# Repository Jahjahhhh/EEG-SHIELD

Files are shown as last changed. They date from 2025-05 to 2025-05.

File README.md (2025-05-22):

# EEG-SHIELD

Electroencephalography (EEG) acquisition system. Using TI's ADS1299-4 low noise, programmable gain amplifier, 4 channel ADC.
The data is sent to a PC using SPI (raspberry pi in this case) to view measured signals. In order to not lose any bits of data, 
we use a microcontroller (ESP32) to interface with the ADS1299 and relay information to the Raspberry Pi 3B+ (the Pi is busy interrupting, it is running an OS).

---

## Project File Structure

| Folder | Contents |
|---|---|
| `KiCAD/` | Main KiCad project files |
| `KiCAD/gerbers`  | KiCad gerber files |
| `KiCAD/images` | Images used in KiCad |
| `KiCAD/libraries`| KiCad footprints and symbols |
| `PDFs/` | Useful PDFs for the project |
| `images/` | Images for the Github repository |
| `source/projet6` | The ESP32 code directory |
| `source/projet6/compile-upload-monitor.sh` | Script to build and monitor arduino script  |
| `source/projet6/definitions.h` | #define (register definitions, etc) |
| `source/projet6/functions.h` | Custom functions  |
| `source/projet6/projet6.sh` | Main Arduino sketch, runs the functions in `functions.h`  |
| `source/pi` | The RPi code directory |
| `source/pi/main.py` | Reads data from ESP32 and formats it into data.txt |
| `source/pi/data.txt` | Raw data to be graphed |
| `source/pi/plot.py` | Reads `source/pi/data.txt` to generate a graph |
---

## Images

### Schematics
#### Raspberry Pi 3B+ Circuit
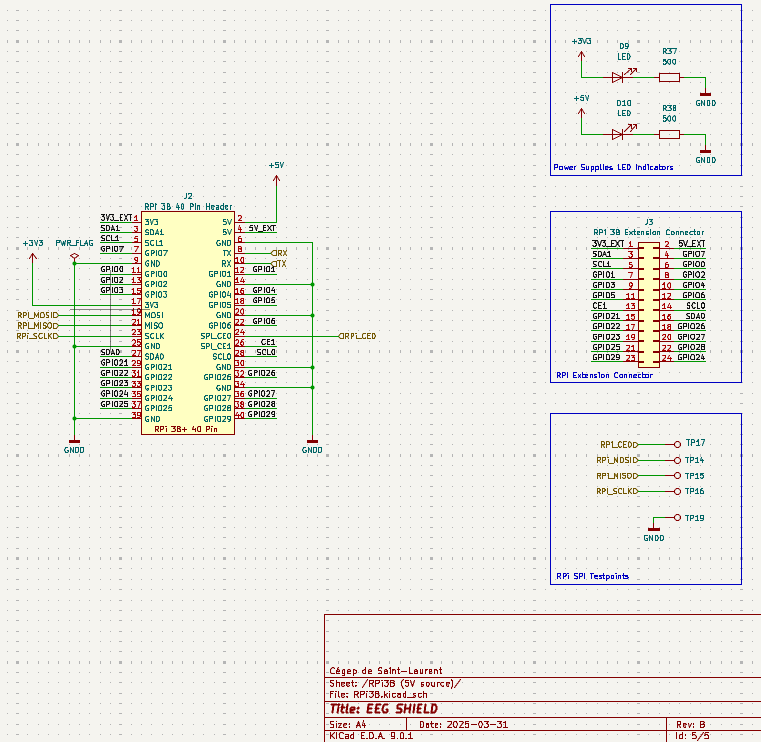
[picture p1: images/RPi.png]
Schematic

#### ESP32 Circuit
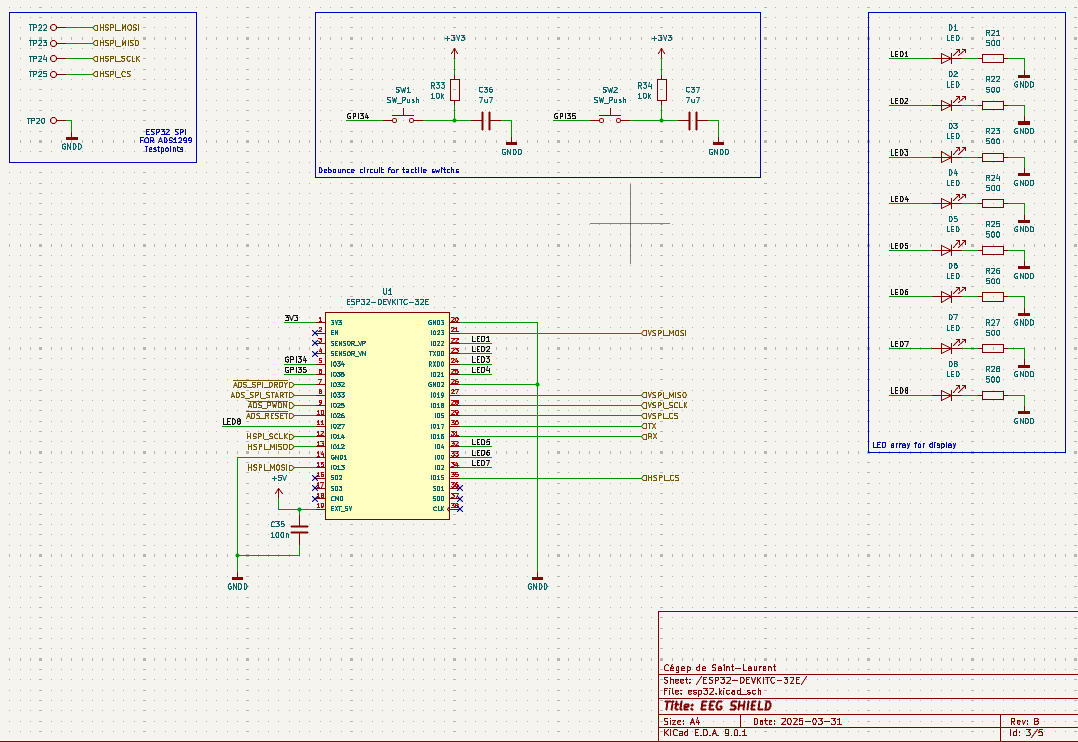
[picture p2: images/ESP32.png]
ESP32

#### Power Circuit
#### it's wrong, please dont send this to the manufacturer, one of the LDOs (U4) needs to be swapped for a TPS73225DBVR (and traces modified)
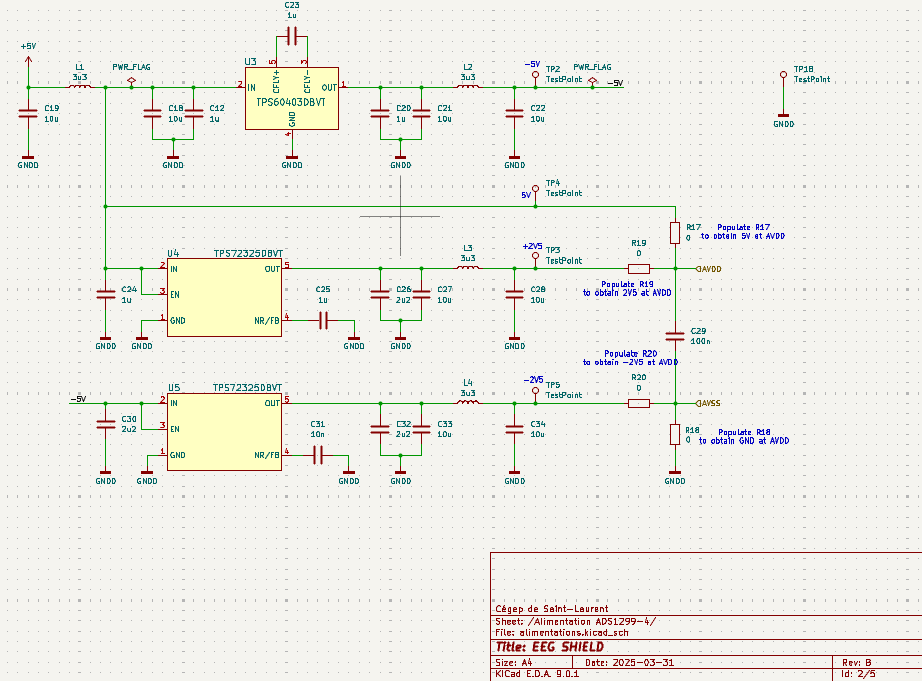
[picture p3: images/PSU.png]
PowerSupply

#### ADS1299-4 Circuit
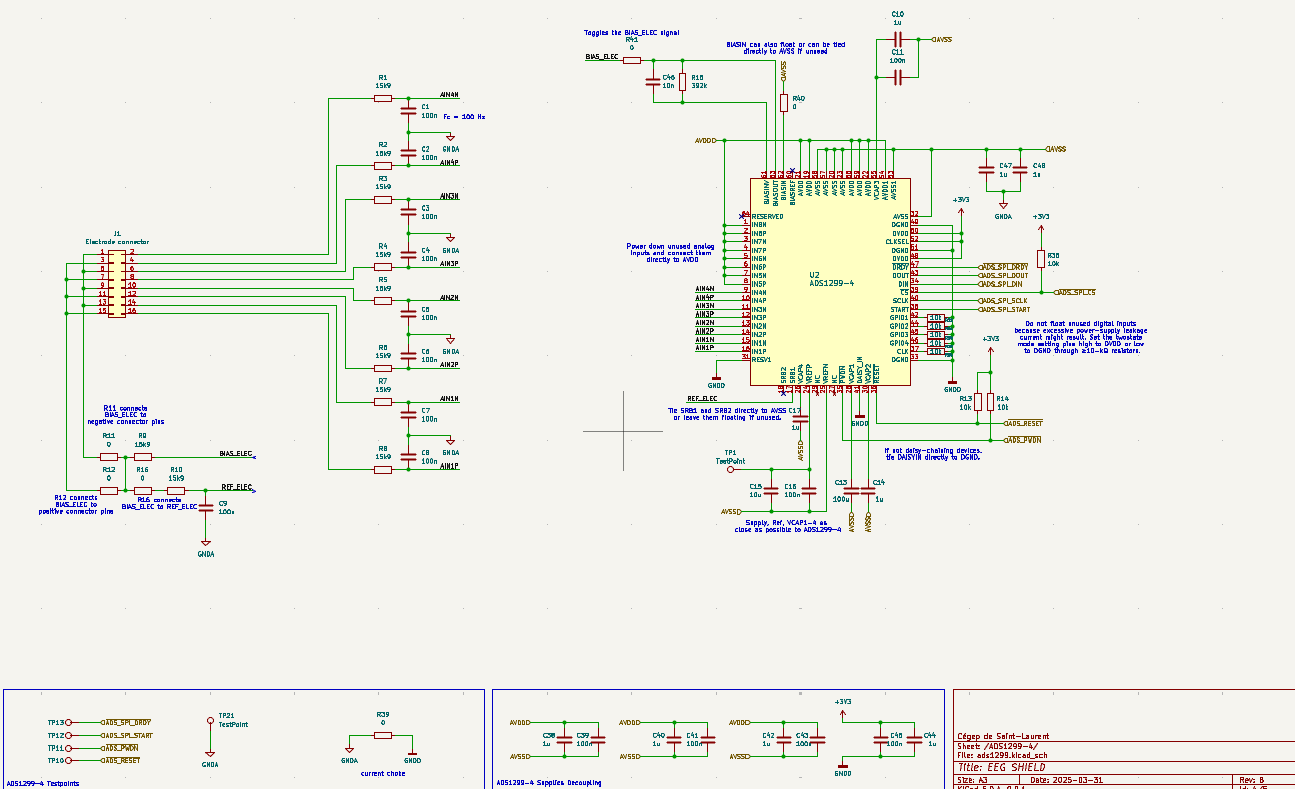
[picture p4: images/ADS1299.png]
ADS1299


### PCB layout
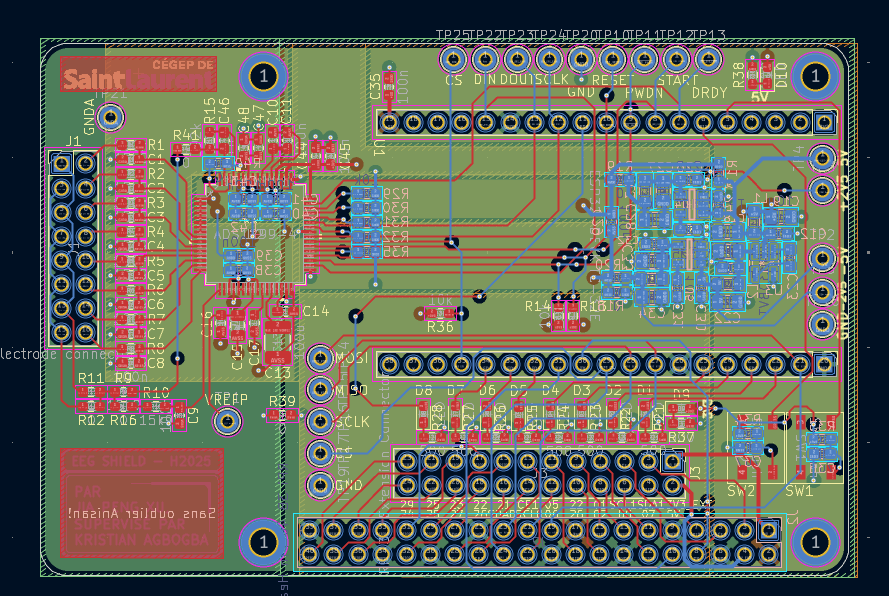
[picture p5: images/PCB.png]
PCB

### 3D render
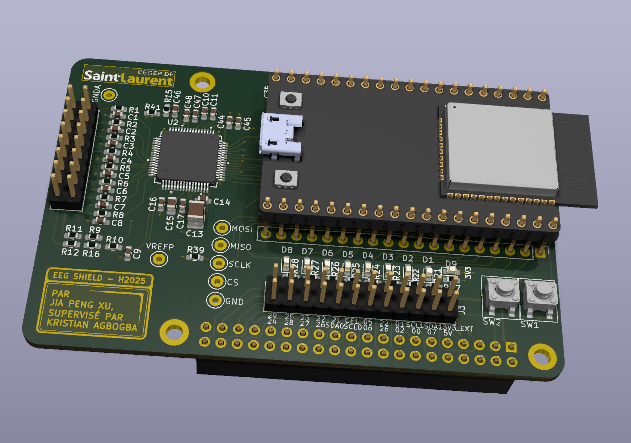
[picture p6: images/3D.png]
3D

### End result
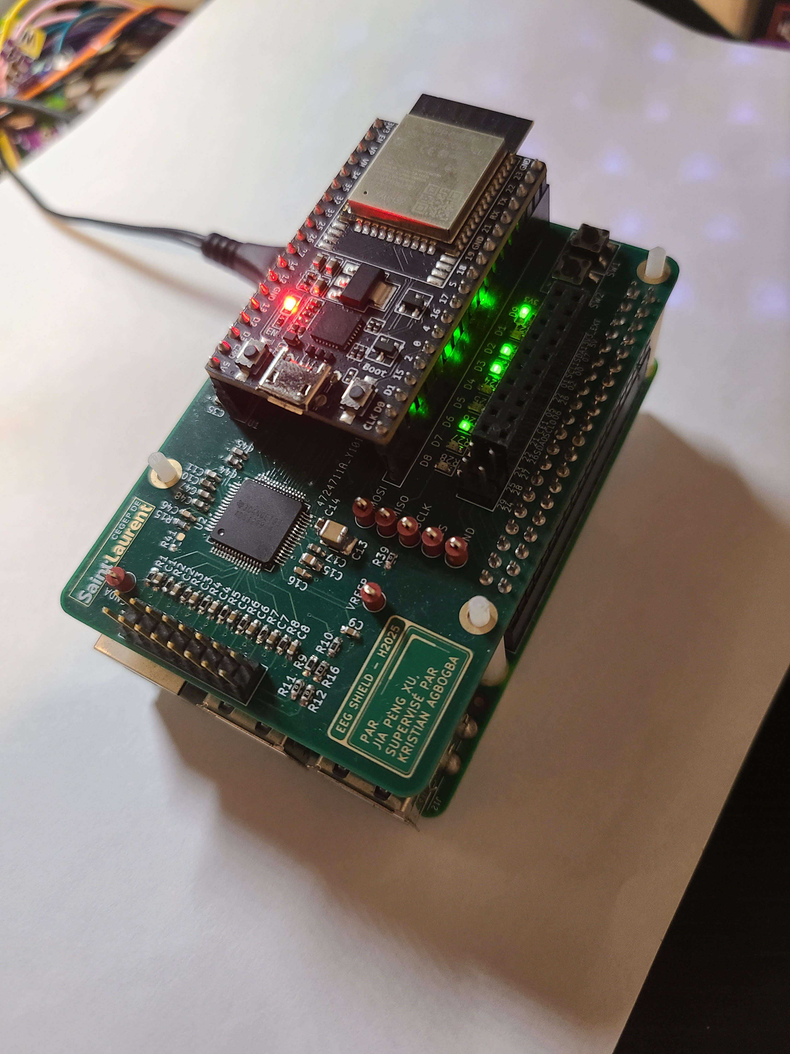
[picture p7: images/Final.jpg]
Final


---

## Tools Used

- KiCad version: 9
- Python 3
- Matplotlib
- Arduino-cli
  - Allows to compile/upload/monitor the pi with a SSH session (Arduino IDE requires a GUI)
  - Can integrate into neovim, since it is just a command
  - Example found in `source/projet6/compile-upload-monitor.sh`

---

## BOM (Bill of Materials)
### IMPORTANT
- The RPi extension connector is a 24 pin connector, not a 20...
- The parts are ordered in 2x, 3x, in case you lose/break the part or they're bad.
- If buying with the cegep, you need electrodes and low impedance gel (example at the end of the BOM)
- TPS73225DBVR missing in the BOM (board will short if you use 2 TPS72325DBVR instead of a TPS72325DBVR and a TPS73225DBVR)
- The BOM is missing the ESP32 socket, buy 2 1x19 PinSocket Headers, 2.54 mm pitch per board, or 1x20 and cut the extra off)

| Qty | Designators | Name/Description | Supplier Link | Footprint |
|---:|:---|:---|:---|:---|
| 3 | J2 | RPi 3B 40 Pin Socket | https://www.digikey.ca/en/products/detail/samtec-inc/ESQ-120-44-T-D/7098774 | PinSocket_2x20_P2.54mm_Vertical |
| 3 | J3 | RPi 3B Extension Connector | https://www.digikey.ca/en/products/detail/sullins-connector-solutions/PPTC102LFBN-RC/810216 | PinHeader_2x12_P2.54mm_Vertical |
| 2 | U2 | ADS1299-4 | https://www.digikey.ca/en/products/detail/texas-instruments/ADS1299-4PAGR/6590685 | PAG64_TEX |
| 34 | C45,C43,C41,C39,C35,C29,C16,C11,C9,C8,C7,C6,C5,C4,C3,C2,C1 | 100n | https://www.digikey.ca/en/products/detail/kemet/C0603C104K5RAC7411/3317013 | C_0603_1608Metric_Pad1.08x0.95mm_HandSolder |
| 20 | R6,R10,R9,R8,R7,R5,R4,R3,R2,R1 | 15k9 | https://www.digikey.ca/en/products/detail/yageo/RC0603FR-0715K8L/726957 | R_0603_1608Metric_Pad0.98x0.95mm_HandSolder |
| 6 | U5,U4 | TPS72325DBVT | https://www.digikey.ca/en/products/detail/texas-instruments/TPS72325DBVR/1672727 | DBV0005A |
| 3 | U3 | TPS60403DBVT | https://www.digikey.ca/en/products/detail/texas-instruments/TPS60403DBVT/484639 | DBV5 |
| 2 | U1 | ESP32-DEVKITC-32E | https://www.digikey.ca/en/products/detail/espressif-systems/ESP32-DEVKITC-32E/12091810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 | ESP32-DEVKITC-32E |
| 21 | TP25,TP24,TP23,TP22,TP21,TP20,TP19,TP18,TP17,TP16,TP15,TP14,TP13,TP12,TP11,TP10,TP5,TP4,TP3,TP2,TP1 | TestPoint | https://www.digikey.ca/en/products/detail/keystone-electronics/5000/255326 | TestPoint_Keystone_5000-5004_Miniature |
| 4 | SW2,SW1 | SW_Push | https://www.digikey.ca/en/products/detail/c-k/PTS647SK38SMTR2-LFS/9649862 | PTS647SK38SMTR2 |
| 36 | R41,R40,R20,R19,R18,R17,R16,R12,R11 | 0 | https://www.digikey.ca/en/products/detail/yageo/RC0603JR-070RL/726675 | R_0603_1608Metric_Pad0.98x0.95mm_HandSolder |
| 20 | R38,R37,R28,R27,R26,R25,R24,R23,R22,R21 | 500 | https://www.digikey.ca/en/products/detail/vishay-dale/RCS0603510RFKEA/5868452 | R_0603_1608Metric_Pad0.98x0.95mm_HandSolder |
| 20 | R36,R35,R34,R33,R32,R31,R30,R29,R14,R13 | 10k | https://www.digikey.ca/en/products/detail/yageo/RC0603FR-0710KL/726880 | R_0603_1608Metric_Pad0.98x0.95mm_HandSolder |
| 3 | R15 | 392k | https://www.digikey.ca/en/products/detail/stackpole-electronics-inc/RMCF0603FT392K/1760716 | R_0603_1608Metric_Pad0.98x0.95mm_HandSolder |
| 8 | L4,L3,L2,L1 | 3u3 | https://www.digikey.ca/en/products/detail/tdk-corporation/MLZ2012A3R3WT000/2465152 | L_0805_2012Metric_Pad1.05x1.20mm_HandSolder |
| 3 | J1 | Electrode connector | https://www.digikey.ca/en/products/detail/amphenol-cs-fci/10129381-916001BLF/7916090 | PinHeader_2x08_P2.54mm_Vertical |
| 30 | D10,D9,D8,D7,D6,D5,D4,D3,D2,D1 | LED | https://www.digikey.ca/en/products/detail/liteon/LTST-C190GKT/269230 | LED_0603_1608Metric_Pad1.05x0.95mm_HandSolder |
| 28 | C48,C47,C44,C42,C40,C38,C25,C24,C23,C20,C17,C14,C12,C10 | 1u | https://www.digikey.ca/en/products/detail/taiyo-yuden/TMK107BJ105KA-T/930600 | C_0603_1608Metric_Pad1.08x0.95mm_HandSolder |
| 6 | C46,C31 | 10n | https://www.digikey.ca/en/products/detail/kemet/C0603C103K5RACTU/411090 | C_0603_1608Metric_Pad1.08x0.95mm_HandSolder |
| 6 | C37,C36 | 7u7 | https://www.digikey.ca/en/products/detail/samsung-electro-mechanics/CL10A475KO8NNNC/3887442 | C_0603_1608Metric_Pad1.08x0.95mm_HandSolder |
| 18 | C34,C33,C28,C27,C22,C21,C19,C18,C15 | 10u | https://www.digikey.ca/en/products/detail/samsung-electro-mechanics/CL21A106KPFNNNE/3886710 | C_0805_2012Metric_Pad1.18x1.45mm_HandSolder |
| 12 | C32,C30,C26 | 2u2 | https://www.digikey.ca/en/products/detail/samsung-electro-mechanics/CL10A225KQ8NNWC/3887544 | C_0603_1608Metric_Pad1.08x0.95mm_HandSolder |
| 3 | C13 | 100u | https://www.digikey.ca/en/products/detail/murata-electronics/GRM32ER61A107ME20L/4905633 | C_1210_3225Metric_Pad1.33x2.70mm_HandSolder |
| 1 | nan | Ten20 EEG Conductive Gel | https://www.redskymedical.ca/products/ten-20-conductive?_pos=1&_sid=2f7834543&_ss=r | nan |
| 1 | nan | Gold cup electrodes | https://shop.openbci.com/products/openbci-gold-cup-electrodes | nan |

---

## Author & Contributions

- Project by Jia Peng Xu
- Supervised by Kristian M. Agbogba

---
## Future considerations
- Use something else than an ESP32, they're running FreeRTOS under the hood! Did not know this at the time. Will use something like an STM32 or an Atmel micro next time.

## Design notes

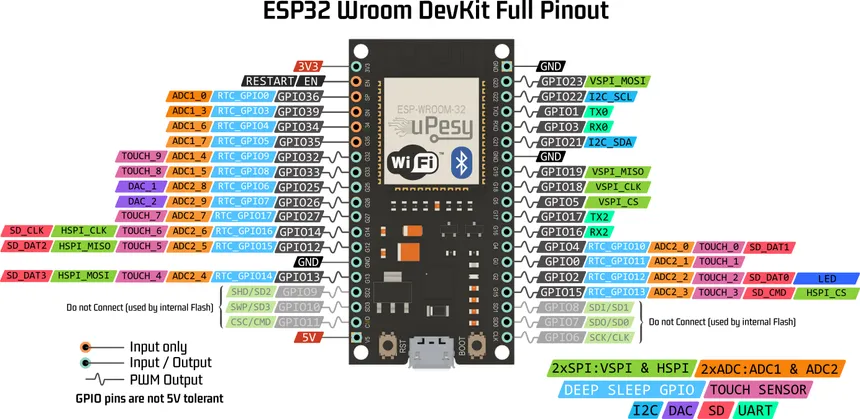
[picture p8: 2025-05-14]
KiCAD/images/ESP32-DEVKITC-32E Pinout.webp

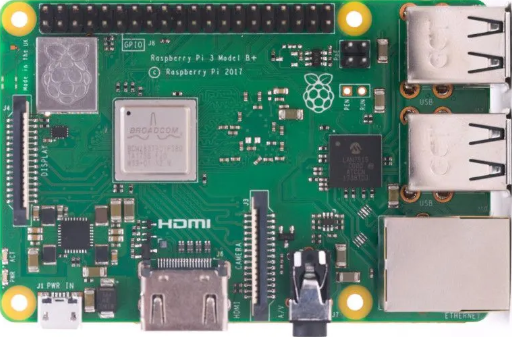
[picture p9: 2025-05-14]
KiCAD/images/RPi3B.png

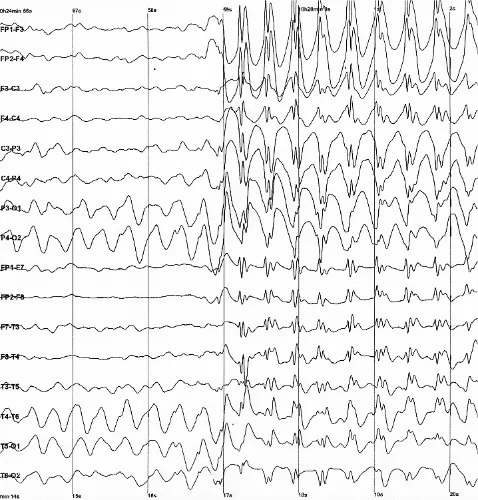
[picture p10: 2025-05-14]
KiCAD/images/eegwaves.png

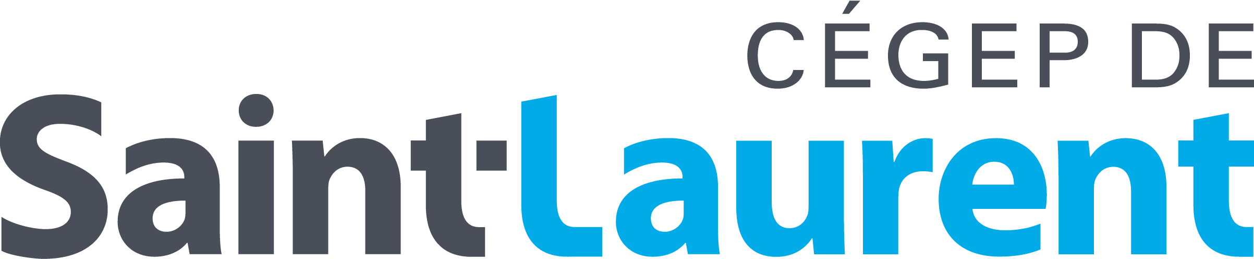
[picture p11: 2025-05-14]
KiCAD/images/stlo.png

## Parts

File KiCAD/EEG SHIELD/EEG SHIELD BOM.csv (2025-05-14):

Id | Designator | Footprint | Quantity | Designation | Supplier and ref
1 | J2 | PinSocket_2x20_P2.54mm_Vertical | 1 | ~
2 | J3 | PinHeader_2x12_P2.54mm_Vertical | 1 | RPi 3B Extension Connector
3 | U2 | PAG64_TEX | 1 | ADS1299-4
4 | C5,C2,C45,C43,C41,C39,C35,C29,C16,C11,C9,C8,C7,C6,C4,C3,C1 | C_0603_1608Metric_Pad1.08x0.95mm_HandSolder | 17 | 100n
5 | R6,R10,R9,R8,R7,R5,R4,R3,R2,R1 | R_0603_1608Metric_Pad0.98x0.95mm_HandSolder | 10 | 15k9
6 | U5,U4 | DBV0005A | 2 | TPS72325DBVT
7 | U3 | DBV5 | 1 | TPS60403DBVT
8 | U1 | ESP32-DEVKITC-32E | 1 | ESP32-DEVKITC-32E
9 | TP25,TP24,TP23,TP22,TP21,TP20,TP19,TP18,TP17,TP16,TP15,TP14,TP13,TP12,TP11,TP10,TP5,TP4,TP3,TP2,TP1 | TestPoint_Keystone_5000-5004_Miniature | 21 | TestPoint
10 | SW2,SW1 | PTS647SK38SMTR2 | 2 | SW_Push
11 | R41,R40,R20,R19,R18,R17,R16,R12,R11 | R_0603_1608Metric_Pad0.98x0.95mm_HandSolder | 9 | 0
12 | R38,R37,R28,R27,R26,R25,R24,R23,R22,R21 | R_0603_1608Metric_Pad0.98x0.95mm_HandSolder | 10 | 500
13 | R36,R35,R34,R33,R32,R31,R30,R29,R14,R13 | R_0603_1608Metric_Pad0.98x0.95mm_HandSolder | 10 | 10k
14 | R15 | R_0603_1608Metric_Pad0.98x0.95mm_HandSolder | 1 | 392k
15 | L4,L3,L2,L1 | L_0805_2012Metric_Pad1.05x1.20mm_HandSolder | 4 | 3u3
16 | J1 | PinHeader_2x08_P2.54mm_Vertical | 1 | Electrode connector
17 | D10,D9,D8,D7,D6,D5,D4,D3,D2,D1 | LED_0603_1608Metric_Pad1.05x0.95mm_HandSolder | 10 | LED
18 | C48,C47,C44,C42,C40,C38,C25,C24,C23,C20,C17,C14,C12,C10 | C_0603_1608Metric_Pad1.08x0.95mm_HandSolder | 14 | 1u
19 | C46,C31 | C_0603_1608Metric_Pad1.08x0.95mm_HandSolder | 2 | 10n
20 | C37,C36 | C_0603_1608Metric_Pad1.08x0.95mm_HandSolder | 2 | 7u7
21 | C34,C33,C28,C27,C22,C21,C19,C18,C15 | C_0805_2012Metric_Pad1.18x1.45mm_HandSolder | 9 | 10u
22 | C32,C30,C26 | C_0603_1608Metric_Pad1.08x0.95mm_HandSolder | 3 | 2u2
23 | C13 | C_1210_3225Metric_Pad1.33x2.70mm_HandSolder | 1 | 100u

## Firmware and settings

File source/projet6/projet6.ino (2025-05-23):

#include <SPI.h>
#include "functions.h"
#include "definitions.h"

volatile bool dataReady = false;

void onDRDY() {
  dataReady = true;
}

void setup() {
  pin_init();
  serial_init(1000000);
  hspi_init();
  reset_reg_values();

  delay(5000); // this gotta be long enough

  write_reg(CONFIG3_ADDR, 0b11100000);
  write_reg(CONFIG1_ADDR, 0b11010100);
  write_reg(CONFIG2_ADDR, 0b11010000);
  write_reg(CH1SET_ADDR, 0b00000000);
  write_reg(CH2SET_ADDR, 0b00000000);
  write_reg(CH3SET_ADDR, 0b00000000);
  write_reg(CH4SET_ADDR, 0b00000000);

  uint8_t res1 = read_reg(CH1SET_ADDR);
  uint8_t res2 = read_reg(CH2SET_ADDR);
  uint8_t res3 = read_reg(CH3SET_ADDR);
  uint8_t res4 = read_reg(CH4SET_ADDR);
  Serial.print(res1); Serial.print(" ");
  Serial.print(res2); Serial.print(" ");
  Serial.print(res3); Serial.print(" ");
  Serial.println(res4);
  
  attachInterrupt(digitalPinToInterrupt(DRDY_PIN), onDRDY, FALLING);
  delay(100);

  digitalWrite(START_PIN, HIGH);

  digitalWrite(H_CS_PIN, LOW);
  delayMicroseconds(2);
  hspi.beginTransaction(SPISettings(SPI_CLK, MSBFIRST, SPI_MODE1));
  delayMicroseconds(2);
  hspi.transfer(RDATAC_CMD);
  delayMicroseconds(2);
  hspi.endTransaction();
  digitalWrite(H_CS_PIN, HIGH);
}

void loop() {
  if(dataReady) {
    dataReady = false;

    byte data[15] = {0}; // 3 status bytes + 4 channels * 3 bytes = 15 bytes total
    digitalWrite(H_CS_PIN, LOW);
    for(int i = 0; i < 15; i++) {
      data[i] = hspi.transfer(0);
    }
    digitalWrite(H_CS_PIN, HIGH);

    int32_t status_bits24 = ((int32_t)data[0] << 16) | ((int32_t)data[1] << 8) | data[2];
    int32_t chan1_bits24  = ((int32_t)data[3] << 16) | ((int32_t)data[4] << 8) | data[5];
    int32_t chan2_bits24  = ((int32_t)data[6] << 16) | ((int32_t)data[7] << 8) | data[8];
    int32_t chan3_bits24  = ((int32_t)data[9] << 16) | ((int32_t)data[10] << 8) | data[11];
    int32_t chan4_bits24  = ((int32_t)data[12] << 16) | ((int32_t)data[13] << 8) | data[14];

    int32_t chan1_bits32 = convert24To32bit(chan1_bits24);
    int32_t chan2_bits32 = convert24To32bit(chan2_bits24);
    int32_t chan3_bits32 = convert24To32bit(chan3_bits24);
    int32_t chan4_bits32 = convert24To32bit(chan4_bits24);

    int32_t channels[4] = {chan1_bits32, chan2_bits32, chan3_bits32, chan4_bits32};
    //Serial.write((uint8_t*)channels, sizeof(channels));
    Serial.print(chan1_bits32); Serial.print(" ");
    Serial.print(chan2_bits32); Serial.print(" ");
    Serial.print(chan3_bits32); Serial.print(" ");
    Serial.println(chan4_bits32);
  }
}

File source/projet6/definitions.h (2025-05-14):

// HSPI (towards ADS1299-4)
#define H_CS_PIN      15
#define H_SCLK_PIN    14
#define H_MISO_PIN    12
#define H_MOSI_PIN    13
#define DRDY_PIN      32
#define START_PIN     33

// VSPI (towards PI)
#define V_CS_PIN       5
#define V_SCLK_PIN    18
#define V_MISO_PIN    19
#define V_MOSI_PIN    23

// POWER
#define ADS_PWDN_PIN  25
#define ADS_RESET_PIN 26

// LEDs for debugging
#define LED1_PIN      22
#define LED2_PIN       1 // Also TX0
#define LED3_PIN       3 // Also RX0
#define LED4_PIN      21
#define LED5_PIN       4
#define LED6_PIN       0
#define LED7_PIN       2
#define LED8_PIN      27

// SPI Commands
// System Commands
#define WAKEUP_CMD   0x02
#define STANDBY_CMD  0x04
#define RESET_CMD    0x06
#define START_CMD    0x08
#define STOP_CMD     0x0A

// Data Read Commands
#define RDATAC_CMD 0x10 // Read Data Continuously
#define SDATAC_CMD 0x11 // Stop RDATAC
#define RDATA_CMD  0x12 // Read Data by Command

// Register Read Commands (Ignored if RDATAC is enabled)
// RREG: Read  n nnnn registers starting at addr r rrrr, 001r rrrr (2xh), 000n nnnn
#define RREG 0x20 // ex: RREG | 0x00 to start reading at addr 0
// WREG: Write n nnnn registers starting at addr r rrrr, 010r rrrr (4xh), 000n nnnn
#define WREG 0x40 // same was RREG but to write

// Register adresses (to read, gotta send 0x11 SPI CMD first)
// Global Settings Across Channels
#define ID_ADDR      0x0
#define CONFIG1_ADDR 0x1
#define CONFIG2_ADDR 0x2
#define CONFIG3_ADDR 0x3
#define LOFF         0x4

// Channel-Specific Settings
#define CH1SET_ADDR      0x5
#define CH2SET_ADDR      0x6
#define CH3SET_ADDR      0x7
#define CH4SET_ADDR      0x8
#define CH5SET_ADDR      0x9
#define CH6SET_ADDR      0xA
#define CH7SET_ADDR      0xB
#define CH8SET_ADDR      0xC
#define BIAS_SENSP_ADDR  0xD
#define BIAS_SENSN_ADDR  0xE
#define LOFF_SENSP_ADDR  0xF
#define LOFF_SENSN_ADDR 0x10
#define LOFF_FLIP_ADDR  0x11

// Lead-Off Status Registers (Read-Only Registers)
#define LOFF_STATP      0x12
#define LOFF_STATN      0x13

// GPIO and OTHER Registers
#define GPIO_ADDR       0x14
#define MISC1_ADDR      0x15
#define MISC2_ADDR      0x16
#define CONFIG4_ADDR    0x17

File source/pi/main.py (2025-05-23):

import serial

ser = serial.Serial('/dev/ttyUSB0', 1000000, timeout=1)

with open('data.txt', 'w') as f:
    while True:
        line = ser.readline().decode('ascii', errors='ignore').strip()
        parts = line.split()

        if len(parts) == 4 and all(p.isdigit() or (p[0] == '-' and p[1:].isdigit()) for p in parts):
            f.write(f"{parts[0]} {parts[1]} {parts[2]} {parts[3]}\n")

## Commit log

2025-05-14 first actual commit
    [EEG SHIELD BOM.csv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]
2025-05-14 added instructions on how to mount pi filesystem on PC make developpement time faster
2025-05-18 added warning for power supply schematic
    if u dont see this, shame on u
2025-05-18 added picture of the assembled board
2025-05-18 fixed bom markdown table in readme
2025-05-23 fixed timing and broken data
    [capture.py, main.py, peakfreq.py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]
